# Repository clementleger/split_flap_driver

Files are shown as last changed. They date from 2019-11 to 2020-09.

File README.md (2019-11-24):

# Split flap board

Split flap display board for 28BYJ-48 motors
After seeing this design on thingiverse: https://www.thingiverse.com/thing:2369832
I needed to have one so I designed a board to driver multiple of these units.
The board is based on I2C IO expanders and uln2803 since I had these in my drawer.

# PCB

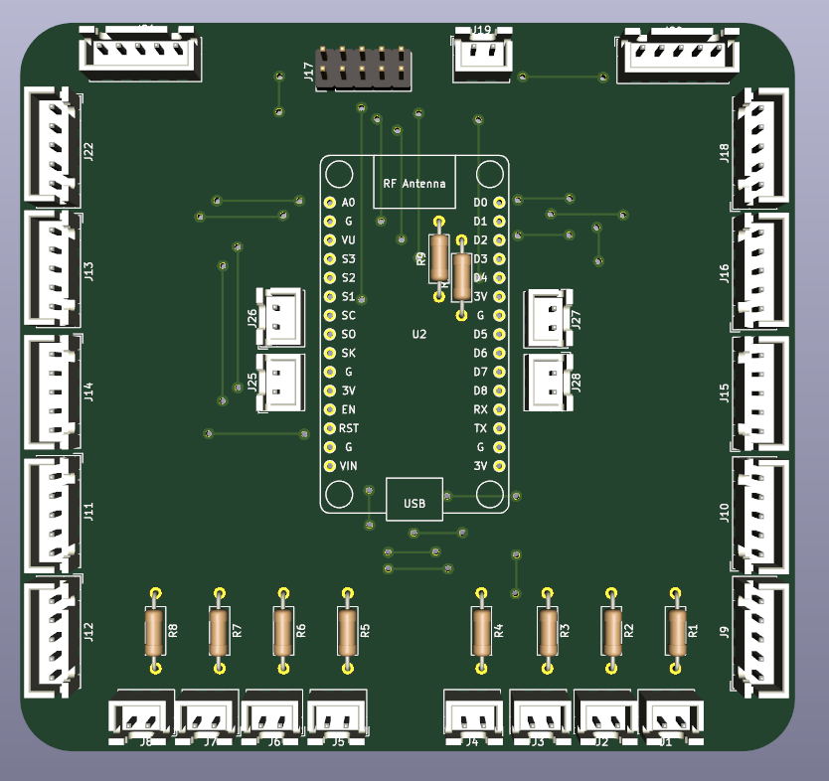
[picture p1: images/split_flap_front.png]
PCB front

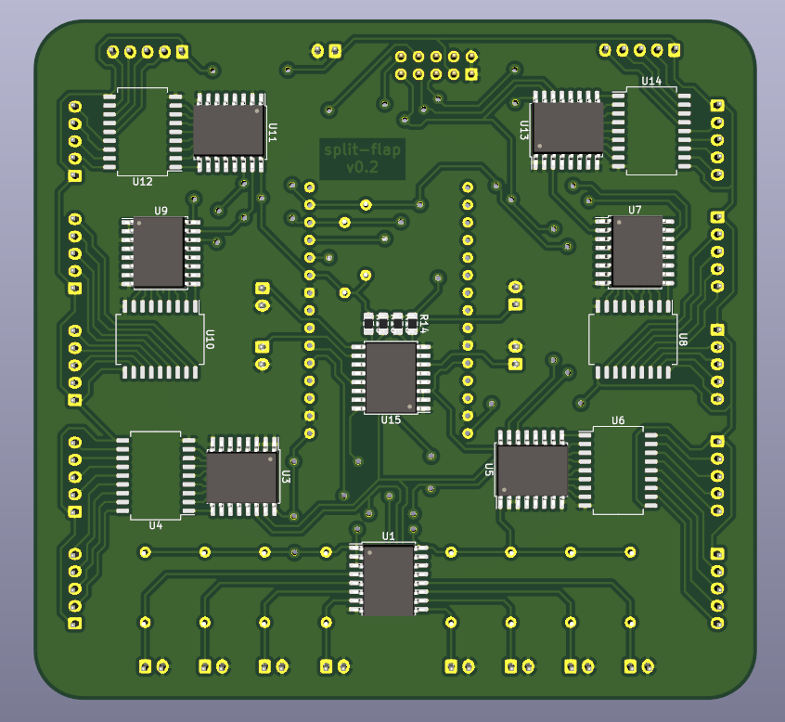
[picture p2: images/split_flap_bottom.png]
PCB bottom


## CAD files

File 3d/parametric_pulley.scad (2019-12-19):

// Parametric Pulley with multiple belt profiles
// by droftarts January 2012

// Based on pulleys by:
// http://www.thingiverse.com/thing:11256 by me!
// https://github.com/prusajr/PrusaMendel by Josef Prusa
// http://www.thingiverse.com/thing:3104 by GilesBathgate
// http://www.thingiverse.com/thing:2079 by nophead

// dxf tooth data from http://oem.cadregister.com/asp/PPOW_Entry.asp?company=915217&elementID=07807803/METRIC/URETH/WV0025/F
// pulley diameter checked and modelled from data at http://www.sdp-si.com/D265/HTML/D265T016.html


module pulley(teeth = 8,
profile = 6,

motor_shaft = 5.2,
m3_dia = 3.2,
m3_nut_hex = 1,
m3_nut_flats = 5.7,
m3_nut_depth = 2.7,	

retainer = 1,
retainer_ht = 0.4,
idler = 1,
idler_ht = 0.4,

pulley_t_ht = 12,
pulley_b_ht = 0,
pulley_b_dia = 20,
no_of_nuts = 0,
nut_angle = 90,
nut_shaft_distance = 1.2) {

// tuneable constants




//	********************************
//	** Scaling tooth for good fit **
//	********************************
/*	To improve fit of belt to pulley, set the following constant. Decrease or increase by 0.1mm at a time. We are modelling the *BELT* tooth here, not the tooth on the pulley. Increasing the number will *decrease* the pulley tooth size. Increasing the tooth width will also scale proportionately the tooth depth, to maintain the shape of the tooth, and increase how far into the pulley the tooth is indented. Can be negative */

additional_tooth_width = 0.2; //mm

//	If you need more tooth depth than this provides, adjust the following constant. However, this will cause the shape of the tooth to change.

additional_tooth_depth = 0; //mm

// calculated constants

nut_elevation = pulley_b_ht/2;
m3_nut_points = 2*((m3_nut_flats/2)/cos(30)); // This is needed for the nut trap

// The following set the pulley diameter for a given number of teeth

MXL_pulley_dia = tooth_spacing (2.032,0.254);
40DP_pulley_dia = tooth_spacing (2.07264,0.1778);
XL_pulley_dia = tooth_spacing (5.08,0.254);
H_pulley_dia = tooth_spacing (9.525,0.381);
T2_5_pulley_dia = tooth_spaceing_curvefit (0.7467,0.796,1.026);
T5_pulley_dia = tooth_spaceing_curvefit (0.6523,1.591,1.064);
T10_pulley_dia = tooth_spacing (10,0.93);
AT5_pulley_dia = tooth_spaceing_curvefit (0.6523,1.591,1.064);
HTD_3mm_pulley_dia = tooth_spacing (3,0.381);
HTD_5mm_pulley_dia = tooth_spacing (5,0.5715);
HTD_8mm_pulley_dia = tooth_spacing (8,0.6858);
GT2_2mm_pulley_dia = tooth_spacing (2,0.254);
GT2_3mm_pulley_dia = tooth_spacing (3,0.381);
GT2_5mm_pulley_dia = tooth_spacing (5,0.5715);

// The following calls the pulley creation part, and passes the pulley diameter and tooth width to that module

if ( profile == 1 ) { parametric_pulley ( "MXL" , MXL_pulley_dia , 0.508 , 1.321 ); }
if ( profile == 2 ) { parametric_pulley ( "40 D.P." , 40DP_pulley_dia , 0.457 , 1.226 ); }
if ( profile == 3 ) { parametric_pulley ( "XL" , XL_pulley_dia , 1.27, 3.051 ); }
if ( profile == 4 ) { parametric_pulley ( "H" , H_pulley_dia ,1.905 , 5.359 ); }
if ( profile == 5 ) { parametric_pulley ( "T2.5" , T2_5_pulley_dia , 0.7 , 1.678 ); }
if ( profile == 6 ) { parametric_pulley ( "T5" , T5_pulley_dia , 1.19 , 3.264 ); }
if ( profile == 7 ) { parametric_pulley ( "T10" , T10_pulley_dia , 2.5 , 6.13 ); }
if ( profile == 8 ) { parametric_pulley ( "AT5" , AT5_pulley_dia , 1.19 , 4.268 ); }
if ( profile == 9 ) { parametric_pulley ( "HTD 3mm" , HTD_3mm_pulley_dia , 1.289 , 2.27 ); }
if ( profile == 10 ) { parametric_pulley ( "HTD 5mm" , HTD_5mm_pulley_dia , 2.199 , 3.781 ); }
if ( profile == 11 ) { parametric_pulley ( "HTD 8mm" , HTD_8mm_pulley_dia , 3.607 , 6.603 ); }
if ( profile == 12 ) { parametric_pulley ( "GT2 2mm" , GT2_2mm_pulley_dia , 0.764 , 1.494 ); }
if ( profile == 13 ) { parametric_pulley ( "GT2 3mm" , GT2_3mm_pulley_dia , 1.169 , 2.31 ); }
if ( profile == 14 ) { parametric_pulley ( "GT2 5mm" , GT2_5mm_pulley_dia , 1.969 , 3.952 ); }



// Functions

function tooth_spaceing_curvefit (b,c,d)
	= ((c * pow(teeth,d)) / (b + pow(teeth,d))) * teeth ;

function tooth_spacing(tooth_pitch,pitch_line_offset)
	= (2*((teeth*tooth_pitch)/(3.14159265*2)-pitch_line_offset)) ;

// Main Module

module parametric_pulley( belt_type , pulley_OD , tooth_depth , tooth_width )
	{
	echo (str("Belt type = ",belt_type,"; Number of teeth = ",teeth,"; Pulley Outside Diameter = ",pulley_OD,"mm "));
	tooth_distance_from_centre = sqrt( pow(pulley_OD/2,2) - pow((tooth_width+additional_tooth_width)/2,2));
	tooth_width_scale = (tooth_width + additional_tooth_width ) / tooth_width;
	tooth_depth_scale = ((tooth_depth + additional_tooth_depth ) / tooth_depth) ;


//	************************************************************************
//	*** uncomment the following line if pulley is wider than puller base ***
//	************************************************************************

//	translate ([0,0, pulley_b_ht + pulley_t_ht + retainer_ht ]) rotate ([0,180,0])

	difference()
	 {	 
		union()
		{
			//base
	
			if ( pulley_b_ht < 2 ) { echo ("CAN'T DRAW PULLEY BASE, HEIGHT LESS THAN 2!!!"); } else {
				rotate_extrude($fn=pulley_b_dia*2)
				{
						square([pulley_b_dia/2-1,pulley_b_ht]);
						square([pulley_b_dia/2,pulley_b_ht-1]);
						translate([pulley_b_dia/2-1,pulley_b_ht-1]) circle(1);
				}
			}
	
		difference()
			{
			//shaft - diameter is outside diameter of pulley
			
			translate([0,0,pulley_b_ht]) 
			rotate ([0,0,360/(teeth*4)]) 
			cylinder(r=pulley_OD/2,h=pulley_t_ht, $fn=teeth*4);
	
			//teeth - cut out of shaft
		
			for(i=[1:teeth]) 
			rotate([0,0,i*(360/teeth)])
			translate([0,-tooth_distance_from_centre,pulley_b_ht -1]) 
			scale ([ tooth_width_scale , tooth_depth_scale , 1 ]) 
			{
			if ( profile == 1 ) { MXL();}
			if ( profile == 2 ) { 40DP();}
			if ( profile == 3 ) { XL();}
			if ( profile == 4 ) { H();}
			if ( profile == 5 ) { T2_5();}
			if ( profile == 6 ) { T5();}
			if ( profile == 7 ) { T10();}
			if ( profile == 8 ) { AT5();}
			if ( profile == 9 ) { HTD_3mm();}
			if ( profile == 10 ) { HTD_5mm();}
			if ( profile == 11 ) { HTD_8mm();}
			if ( profile == 12 ) { GT2_2mm();}
			if ( profile == 13 ) { GT2_3mm();}
			if ( profile == 14 ) { GT2_5mm();}
			}

			}
			
		//belt retainer / idler
		if ( retainer > 0 ) {translate ([0,0, pulley_b_ht + pulley_t_ht ]) 
		rotate_extrude($fn=teeth*4)  
		polygon([[0,0],[pulley_OD/2,0],[pulley_OD/2 + retainer_ht , retainer_ht],[0 , retainer_ht],[0,0]]);}
		
		if ( idler > 0 ) {translate ([0,0, pulley_b_ht - idler_ht ]) 
		rotate_extrude($fn=teeth*4)  
		polygon([[0,0],[pulley_OD/2 + idler_ht,0],[pulley_OD/2 , idler_ht],[0 , idler_ht],[0,0]]);}
	
		}
	   
		//hole for motor shaft
		translate([0,0,-1])cylinder(r=motor_shaft/2,h=pulley_b_ht + pulley_t_ht + retainer_ht + 2,$fn=motor_shaft*4);
				
		//captive nut and grub screw holes
	
		if ( pulley_b_ht < m3_nut_flats ) { echo ("CAN'T DRAW CAPTIVE NUTS, HEIGHT LESS THAN NUT DIAMETER!!!"); } else {
		if ( (pulley_b_dia - motor_shaft)/2 < m3_nut_depth + 3 ) { echo ("CAN'T DRAW CAPTIVE NUTS, DIAMETER TOO SMALL FOR NUT DEPTH!!!"); } else {
	
			for(j=[1:no_of_nuts]) rotate([0,0,j*nut_angle])
			translate([0,0,nut_elevation])rotate([90,0,0])
	
			union()
			{
				//entrance
				translate([0,-pulley_b_ht/4-0.5,motor_shaft/2+m3_nut_depth/2+nut_shaft_distance]) cube([m3_nut_flats,pulley_b_ht/2+1,m3_nut_depth],center=true);
	
				//nut
				if ( m3_nut_hex > 0 )
					{
						// hex nut
						translate([0,0.25,motor_shaft/2+m3_nut_depth/2+nut_shaft_distance]) rotate([0,0,30]) cylinder(r=m3_nut_points/2,h=m3_nut_depth,center=true,$fn=6);
					} else {
						// square nut
						translate([0,0.25,motor_shaft/2+m3_nut_depth/2+nut_shaft_distance]) cube([m3_nut_flats,m3_nut_flats,m3_nut_depth],center=true);
					}
	
				//grub screw hole
				rotate([0,0,22.5])cylinder(r=m3_dia/2,h=pulley_b_dia/2+1,$fn=8);
			}
		}}
	 }
	   
	}


// Tooth profile modules

module MXL()
	{
	linear_extrude(height=pulley_t_ht+2) polygon([[-0.660421,-0.5],[-0.660421,0],[-0.621898,0.006033],[-0.587714,0.023037],[-0.560056,0.049424],[-0.541182,0.083609],[-0.417357,0.424392],[-0.398413,0.458752],[-0.370649,0.48514],[-0.336324,0.502074],[-0.297744,0.508035],[0.297744,0.508035],[0.336268,0.502074],[0.370452,0.48514],[0.39811,0.458752],[0.416983,0.424392],[0.540808,0.083609],[0.559752,0.049424],[0.587516,0.023037],[0.621841,0.006033],[0.660421,0],[0.660421,-0.5]]);
	}

module 40DP()
	{
	linear_extrude(height=pulley_t_ht+2) polygon([[-0.612775,-0.5],[-0.612775,0],[-0.574719,0.010187],[-0.546453,0.0381],[-0.355953,0.3683],[-0.327604,0.405408],[-0.291086,0.433388],[-0.248548,0.451049],[-0.202142,0.4572],[0.202494,0.4572],[0.248653,0.451049],[0.291042,0.433388],[0.327609,0.405408],[0.356306,0.3683],[0.546806,0.0381],[0.574499,0.010187],[0.612775,0],[0.612775,-0.5]]);
	}
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

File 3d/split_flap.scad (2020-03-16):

include <prism.scad>
include <parametric_pulley.scad>
include <timing_belts.scad>
include <roundedcube.scad>
include <28byj-48.scad>

/* General tolenracy (should be upadate according to 3D printer) */
TOLERANCY = 0.2;
/* Tolerancy for drum axis */
AXIS_TOLERANCY = 0.3;

/* Width of flaps */
CARD_WIDTH = 54;
/* Height of flaps */
CARD_HEIGHT = 85.6;
/* THickness of flaps */
CARD_THICKNESS = 0.380;
/* Flap drum width */
FLAP_DRUM_WIDTH = CARD_WIDTH;
/* Corner around flaps */
FLAP_CORNER_RADIUS = 3;


FRONT_BOTTOM_HEIGHT = 40;
FRONT_BOTTOM_OPEN_HEIGHT = 30;
FRONT_TOP_HEIGHT = 20;

/* Number of flaps on drum */
DRUM_FLAPS_COUNT = 40;
/* Holes for flaps */
DRUM_FLAPS_HOLE_DIAMETER = 2;
assert(DRUM_FLAPS_HOLE_DIAMETER > FLAP_CUT_OFFSET);
/* Offset of flaps hole  from drum side */
DRUM_FLAPS_HOLE_OFFSET = 1;
/* Inner diameter of drum (ie tube connecting both ends) */
DRUM_INNER_DIAMETER = 40;
/* Outer diameter of drum (ie where the flaps insert) */
DRUM_OUTER_DIAMETER = 50;
/* Thickness of side of drum (ie where the flaps insert) */
DRUM_SIDE_THICKNESS = 2.5;

/* Radius of flaps where the flaps are inserted */
DRUM_FLAP_RADIUS = DRUM_OUTER_DIAMETER/2 - DRUM_FLAPS_HOLE_DIAMETER/2 - DRUM_FLAPS_HOLE_OFFSET;


FLAP_SIDE_CUT_HEIGHT = 8;
FLAP_SIDE_CUT_WIDTH = DRUM_SIDE_THICKNESS + 0.2;
FLAP_CUT_OFFSET = DRUM_FLAPS_HOLE_DIAMETER - 0.8;

/* Depth */
DRUM_AXIS_OVERLAP = 1.6;
assert(DRUM_AXIS_OVERLAP < DRUM_SIDE_THICKNESS);
/* Slack around cards (normally unnecessary) */
DRUM_AXIS_EXTRA_WIDTH = 0;

DRUM_AXIS_HEIGHT = CARD_WIDTH + DRUM_AXIS_EXTRA_WIDTH - DRUM_SIDE_THICKNESS + DRUM_AXIS_OVERLAP;
/* Thickness if tube connecting both ends both ends of drum */
DRUM_AXIS_THICKNESS = 0.8;


/* Diameter of rotation axis */
DRUM_CENTER_DIAMETER = 8;
/* Additionnal height of axis*/
DRUM_CENTER_HEIGHT = 10;
DRUM_CENTER_THICKNESS = 3;

/* Plug width */
DRUM_PLUG_WIDTH = 3;
/* Plug height */
DRUM_PLUG_HEIGHT = 6;
/* Plug thickness */
DRUM_PLUG_THICKNESS = 2;
/* Plug inside drum to connect with other end of drum */
/* This will be minus 1 to allow an exact fitting with other side */
DRUM_PLUG_COUNT = 4;

/* Number of tooth of pulley */
DRUM_PULLEY_TEETH = 25;
/* Thickness of pulley */
DRUM_PULLEY_HEIGHT = 3.5;

/* Total width of drum */
DRUM_WIDTH = CARD_WIDTH + DRUM_AXIS_EXTRA_WIDTH + DRUM_PLUG_WIDTH;

/* Magnet (for hall effect sensor) diameter */
DRUM_MAGNET_DIAMETER = 3;
/* Magnet height */
DRUM_MAGNET_HEIGHT = 3;
DRUM_MAGNET_OFFSET_FROM_CENTER = DRUM_INNER_DIAMETER/2 - 2;

$fn = 50;

/* Ziptie width */
ZIPTIE_WIDTH = 3.5;
/* Ziptie thickness */
ZIPTIE_THICKNESS = 1.4;
/* Sizeof side mount */
ZIPTIE_MOUNT_SIDE_WIDTH = 6;
/* Height of mouting base */
ZIPTIE_MOUNT_HEIGHT = 6;
/* Added thickness on top of ziptie hole */
ZIPTIE_MOUNT_ADD_THICKNESS = 1.5;
/* Full ziptie mount thickness */
ZIPTIE_MOUNT_THICKNESS = ZIPTIE_MOUNT_ADD_THICKNESS + ZIPTIE_THICKNESS;

module ziptie_mount() {
    difference() {
        union () {
            difference() {
                cube([ZIPTIE_WIDTH, ZIPTIE_MOUNT_HEIGHT , ZIPTIE_MOUNT_THICKNESS]);
                cube([ZIPTIE_WIDTH, ZIPTIE_MOUNT_HEIGHT , ZIPTIE_THICKNESS]);
            }
            translate([ZIPTIE_WIDTH + ZIPTIE_MOUNT_SIDE_WIDTH, 0, 0]) rotate([0, 0, 90]) prism(ZIPTIE_MOUNT_HEIGHT, ZIPTIE_MOUNT_SIDE_WIDTH,ZIPTIE_MOUNT_THICKNESS);
            translate([-ZIPTIE_MOUNT_SIDE_WIDTH, ZIPTIE_MOUNT_HEIGHT, 0]) rotate([0, 0, -90]) prism(ZIPTIE_MOUNT_HEIGHT, ZIPTIE_MOUNT_SIDE_WIDTH,ZIPTIE_MOUNT_THICKNESS);
        }
        translate([-ZIPTIE_MOUNT_SIDE_WIDTH, ZIPTIE_MOUNT_HEIGHT/2 - ZIPTIE_WIDTH/2, 0]) cube([ZIPTIE_WIDTH + 2 * ZIPTIE_MOUNT_SIDE_WIDTH, ZIPTIE_WIDTH , ZIPTIE_THICKNESS + SMALL_TOLERANCY]);
    }
}


module hole(width, height, thickness)
{
    cylinder(d = width, h = thickness, $fn = 30);
    translate([-width / 2, 0, 0]) cube([width, height, thickness]);
    
    translate([0, height, 0]) cylinder(d = width, h = thickness, $fn = 30);
}

module drum_plug(tolerancy = 0) 
{
    translate([-DRUM_PLUG_WIDTH/2 - tolerancy/2, 0, -DRUM_PLUG_HEIGHT]) {
        cube([DRUM_PLUG_WIDTH + tolerancy, DRUM_PLUG_THICKNESS + tolerancy, DRUM_PLUG_HEIGHT]);
        translate([0, DRUM_PLUG_THICKNESS, 0]) rotate([180, 0, 0]) prism(DRUM_PLUG_WIDTH, DRUM_PLUG_THICKNESS, DRUM_PLUG_HEIGHT / 2);
    }
}

module drum_end_with_holes()
{
    difference() {
        cylinder(d = DRUM_OUTER_DIAMETER, h = DRUM_SIDE_THICKNESS);
        /* Flaps holes */
        for (hole=[1:DRUM_FLAPS_COUNT])
            rotate([0, 0, hole * (360/DRUM_FLAPS_COUNT)  ]) translate([DRUM_FLAP_RADIUS, 0, 0]) cylinder(d = DRUM_FLAPS_HOLE_DIAMETER, h = DRUM_SIDE_THICKNESS);
        /* Axis */
        cylinder(d = DRUM_CENTER_DIAMETER, h = DRUM_SIDE_THICKNESS);
    }
}

module clipsable_male_part(width, height, thickness, clip_count = 5, clip_height = 5, clip_bottom_width = 8, clip_top_width = 10)
{
    difference() {
        linear_extrude(thickness) {
            square([width, height]);
            for (clips=[0:clip_count+1]) {
                translate([clips * (width / (clip_count + 1)), height]) polygon(points = [[clip_bottom_width/2, 0],[clip_top_width/2, clip_height],[-clip_top_width/2, clip_height],[-clip_bottom_width/2, 0]]);
            }
        }
        /* Remove sides */
        translate([-clip_top_width /2, 0, 0]) cube([clip_top_width/2, height + clip_height, thickness]);
        translate([width, 0, 0]) cube([clip_top_width/2, height + clip_height, thickness]);
    }
}

module drum_side(tolerancy = 0)
{
    /* Base with holes for flaps */
    drum_end_with_holes();

    difference() {
        cylinder(d = DRUM_CENTER_DIAMETER + DRUM_CENTER_THICKNESS, h = DRUM_CENTER_HEIGHT, $fn = 50);
        cylinder(d = DRUM_CENTER_DIAMETER, h = DRUM_CENTER_HEIGHT);
    }
    /* Axis */
    difference() {
        cylinder(d = DRUM_INNER_DIAMETER + tolerancy/2, h = DRUM_AXIS_HEIGHT);
        cylinder(d = DRUM_INNER_DIAMETER - DRUM_AXIS_THICKNESS*2 - tolerancy/2, h = DRUM_AXIS_HEIGHT);
    }
    /* Little plugs on top of axis */
    for (hole=[1:DRUM_PLUG_COUNT - 1])
            rotate([0, 0, hole * (360/DRUM_PLUG_COUNT)]) translate([0, -DRUM_INNER_DIAMETER/2 + DRUM_AXIS_THICKNESS, DRUM_AXIS_HEIGHT]) drum_plug(tolerancy);
}

module drum_with_magnet()
{
    difference() {
        drum_side();
        
        /* Magnet hole */
        translate([DRUM_MAGNET_OFFSET_FROM_CENTER - DRUM_MAGNET_DIAMETER/2 - DRUM_AXIS_THICKNESS, 0, 0]) cylinder(d = DRUM_MAGNET_DIAMETER, h = DRUM_MAGNET_HEIGHT);
    }
}

module drum_with_belt()
{
    difference() {
        translate([0, 0, CARD_WIDTH + DRUM_AXIS_EXTRA_WIDTH - DRUM_SIDE_THICKNESS]) {
            drum_end_with_holes();
            translate([0, 0, DRUM_SIDE_THICKNESS]) pulley(teeth = DRUM_PULLEY_TEETH, profile = 12, motor_shaft = DRUM_CENTER_DIAMETER, pulley_t_ht = DRUM_PULLEY_HEIGHT);
        }
       
    drum_side(TOLERANCY);
    }
}

module cube_rounded(width, height, thickness)
{
    cube([width, height, thickness]);
    translate([0, height, 0]) cylinder(r = width, h = thickness ); 
}

module flap()
{
    difference() {
        hull() {
            cube([CARD_WIDTH, CARD_HEIGHT/2 - FLAP_CORNER_RADIUS, CARD_THICKNESS]);
            translate([FLAP_CORNER_RADIUS, CARD_HEIGHT/2 - FLAP_CORNER_RADIUS, 0]) cylinder(r = FLAP_CORNER_RADIUS, h = CARD_THICKNESS);
            translate([CARD_WIDTH - FLAP_CORNER_RADIUS, CARD_HEIGHT/2 - FLAP_CORNER_RADIUS, 0]) cylinder(r = FLAP_CORNER_RADIUS, h = CARD_THICKNESS);
        }
        translate([CARD_WIDTH, FLAP_CUT_OFFSET, 0]) mirror([1, 0, 0]) cube_rounded(FLAP_SIDE_CUT_WIDTH,FLAP_SIDE_CUT_HEIGHT,CARD_THICKNESS);
        translate([0, FLAP_CUT_OFFSET, 0]) cube_rounded(FLAP_SIDE_CUT_WIDTH,FLAP_SIDE_CUT_HEIGHT,CARD_THICKNESS);
    }
}

HANGING_FLAPS_COUNT = DRUM_FLAPS_COUNT/2;

module flaps()
{
    /* Flaps hanging in the bottom of the drum */
    for (flap=[0:HANGING_FLAPS_COUNT-1]) {
        translate([DRUM_FLAP_RADIUS * sin(flap * (360 / DRUM_FLAPS_COUNT)), DRUM_FLAP_RADIUS * cos(flap * (360 / DRUM_FLAPS_COUNT)), DRUM_AXIS_EXTRA_WIDTH/2]) rotate([0, 0, -90]) 
    rotate([0, -90, 0])  flap();
    }
    for (flap=[HANGING_FLAPS_COUNT:DRUM_FLAPS_COUNT - 1]) {
        translate([DRUM_FLAP_RADIUS * sin(flap * (360 / DRUM_FLAPS_COUNT)), DRUM_FLAP_RADIUS * cos(flap * (360 / DRUM_FLAPS_COUNT)), DRUM_AXIS_EXTRA_WIDTH/2]) rotate([0, 0, - (360 - 90) - flap * (360 / (DRUM_FLAPS_COUNT - 1))]) 
    rotate([0, -90, 0])  flap();
    }
    
}

module drum()
{
    color("grey") drum_side();
    color("grey") drum_with_belt();
    color("white") flaps();
}

/* Size of bottom border */
DISP_BOTTOM_SIZE = 12;
/* Size of top border */
DISP_TOP_SIZE = 16;
/* Add some slack to sides */
DISP_BORDER_ADJUST = 0.8;
DISP_BORDER_SIZE = DRUM_PULLEY_HEIGHT + DISP_BORDER_ADJUST;
assert(DISP_BORDER_SIZE >= DRUM_PULLEY_HEIGHT);

/* Thickness of front part */
FRONT_THICKNESS = 3;
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

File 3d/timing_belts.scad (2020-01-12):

/*Parametric belting section generator 
 * types GT2 2mm T2.5 T5 T10 MXL
 *
 * (c) ALJ_rprp
 *
 * Derived from http://www.thingiverse.com/
 * thing:19758 By The DoomMeister
 * thing:16627 by Droftarts
 *
 * licence GPL 2.1 or later
 *
 * deal properly with ends
 * allow circular segments
 * length is given in mm not nb of teeth
 * belt is centered at z=0 and extend along x
 * 
 * TODO : add ofset for cosmetic teeth liaisons between segments
 *
 * usage :
 * belt_angle(prf = tT2_5, rad=25, bwdth = 6, angle=90,fn=128)
 * belt_len  (prf = tT2_5, belt_width = 6, len = 10)
 */


// profiles
tGT2_2=0;
tT2_5	=1;
tT5	=2;
tT10	=3;
tMXL	=4;

module test_belt() {
	translate([-00.5,0,5.5])cube([1,40,1]);
	
	belt_len(profile = tT10, belt_width = 10, len = 100);
	translate([0,0,-20])color("red")belt_len(profile = tT5, belt_width = 10, len = 100);
	translate([0,0,-40])color("green")belt_len(profile = tT2_5, belt_width = 10, len = 80);
	translate([0,0,-60])color("blue")belt_len(profile = tGT2_2, belt_width = 10, len = 100);
	translate([0,0,-80])color("orange")belt_len(profile = tMXL, belt_width = 10, len = 100);
	
	translate([0,0,-0])  belt_angle(tT10,20,10,180);
	translate([0,0,-20]) belt_angle(tT5,15,10,90);
	translate([0,0,-40]) belt_angle(tT2_5,25,10,120);
	translate([0,0,-60]) belt_angle(tGT2_2,30,10,40);
	translate([0,0,-80]) belt_angle(tMXL,30,10,40);

	
	translate([0,0,-100])color("aquamarine") {
		belt_len(tT2_5,10, 50);
		translate([50,30,0]) rotate([0,0,180]) belt_len(tT2_5,10,50);
		translate([ 0,30,0]) rotate([0,0,180]) belt_angle(tT2_5,15,10,180);
		translate([50,0,0]) rotate([0,0,0]) belt_angle(tT2_5,15,10,180);
	}
}

/* there is no partial rotate extrude in scad, hence the workaround
 * note that the pie slice will silently drop angles > 360 */
module p_slice(radius, angle,height,back_t=0.6) {
	pt_slc = [[0,radius],
		 		 [0 ,-back_t],
		 		 [radius,-back_t],
		 		 [radius+back_t,radius],
		 		 [radius+back_t,radius*2],
				 [0,radius*2+back_t],
				 [-radius-back_t,radius*2+back_t],
				 [-radius-back_t,radius],
				 [-radius-back_t,-back_t],
		 		 [(radius+back_t)*sin(angle),(radius+back_t)*(1-cos(angle))-back_t]];

	if (angle<=90) {
		linear_extrude(height+0.2, center=true)
			polygon( points = pt_slc, 
						paths=[[0,1,2,9]]);
	}else if (angle<=180){
		linear_extrude(height+0.2, center=true)
			polygon( points = pt_slc,  
						paths=[[0,1,2,3,4,9]]);
	}else if (angle<=270){
		linear_extrude(height+0.2, center=true)
			polygon( points = pt_slc,  
						paths=[[0,1,2,3,4,5,6,9]]);
	}else if (angle<360) {
		linear_extrude(height+0.2, center=true)
			polygon( points = pt_slc,  
						paths=[[0,1,2,3,4,5,6,7,8,9]]);
	}
}

dp=5;

module belt_angle(prf = tT2_5, rad=25, bwdth = 6, angle=90,fn=128) {
	av=360/2/rad/3.14159*tpitch[prf];
	bk=bk_thick[prf];

	nn=ceil(angle/av);
	ang=av*nn;
	intersection(){
	p_slice(rad,angle,bwdth,bk_thick[prf]);
		union () {
			for( i = [0:nn]){
				translate ([0,rad,-bwdth/2])rotate ([0,0,av*i])translate ([0,-rad,0])
						draw_tooth(prf,0,bwdth);
		}
		translate ([0,rad,-bwdth/2]) rotate_extrude(angle = 90, $fn=fn)
												polygon([[rad,0],[rad+bk,0],[rad+bk,bwdth],[rad,bwdth]]);
		}
	}
}

//Outer Module
module belt_len(profile = tT2_5, belt_width = 6, len = 10){
	if ( profile == tT2_5 ) { _belt_len(prf=profile,len = len,bwdth = belt_width);}
	if ( profile == tT5 )   { _belt_len(prf=profile,len = len,bwdth = belt_width);}
	if ( profile == tT10 )  { _belt_len(prf=profile,len = len,bwdth = belt_width);}
	if ( profile == tMXL )	{ _belt_len(prf=profile,len = len,bwdth = belt_width);}
	if ( profile == tGT2_2 ){ _belt_len(prf=profile,len = len,bwdth = belt_width);}
}

//inner module
module _belt_len(prf = -1, len = 10, bwdth = 5) {

	n=ceil(len/tpitch[prf]);

	translate ([0,0,-bwdth/2]) intersection() {
		union(){
			for( i = [0:n]) {
				draw_tooth(prf,i,bwdth);
			}
		translate([-1,-bk_thick[prf],0])cube([len+1,bk_thick[prf],bwdth]);
		}
	translate([0,-bk_thick[prf],0])cube([len,max_h[prf]+bk_thick[prf],bwdth]);
	}
}

module draw_tooth(prf,i,bwdth) {
				if ( prf == tT2_5 ) { translate([tpitch[prf]*i,0,0])
													linear_extrude(height=bwdth) polygon(pf_T2_5);}
				if ( prf == tT5 ) { translate([tpitch[prf]*i,0,0])
													linear_extrude(height=bwdth) polygon(pf_T5);}
				if ( prf == tT10 ) { translate([tpitch[prf]*i,0,0])
													linear_extrude(height=bwdth) polygon(pf_T10);}
				if ( prf == tMXL ) { translate([tpitch[prf]*i,0,0])
													linear_extrude(height=bwdth) polygon(pf_MXL);}
				if ( prf == tGT2_2 ) { translate([tpitch[prf]*i,0,0])
													linear_extrude(height=bwdth) polygon(pf_GT2_2);}
}

/************************************
 *				DATA TABLES					*
 ************************************/
tpitch = [2,2.5,5,10,2.032];
bk_thick=[0.6,0.6,1,2,0.64];
max_h=[0.76447, 0.699911, 1.189895, 2.499784, 0.508035];
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

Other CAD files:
3d/28byj-48.scad
3d/prism.scad

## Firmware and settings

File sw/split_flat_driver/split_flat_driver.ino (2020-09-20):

//#define HAVE_WIFI

#include <ESP8266WiFi.h>
#include <ESP8266WebServer.h>
#include <ESP8266mDNS.h>
#include <Arduino.h>
#include <Wire.h>
#include <SPI.h>
#include "c_types.h"
#ifdef HAVE_WIFI
#include "wifi_params.h"
#endif

#define ARRAY_SIZE(arr) (sizeof(arr) / sizeof((arr)[0]))
#define PCF8574_BASE_ADDR	0x20
#define SPI_FREQUENCY	1000000
#define SPI_SR_CS	D8

/* Shared interrupt */
#define INPUT_EXP_INT	D3
#define INPUT_EXP1_ADDR	(PCF8574_BASE_ADDR)

#define STEP_DELAY_US	2000
#define NUM_COILS	4
#define MAX_CHARS	64

#define PCF8574_INPUT_COUNT	8

#define STEPS_PER_REV		2038
#define STEPS_PER_LETTER	(STEPS_PER_REV / ARRAY_SIZE(flaps_chars))

#define SPLITFLAP_DNS_NAME	"splitflap"

enum display_state {
	DISPLAY_IDLE,
	DISPLAY_SYNCING,
	DISPLAY_UPDATING,
	DISPLAY_SERIAL_RECV,
};

static const char flaps_chars[] =
{
	'a', 'b', 'c', 'd', 'e', 'f', 'g', 'h', 'i', 'j', 'k', 'l', 'm', 'n', 'o',
	'p', 'q', 'r', 's', 't', 'u', 'v', 'w', 'x', 'y', 'z',
	'1', '2', '3', '4', '5', '6', '7', '8', '9',
	'#', ',', ':', '*', ' '
};

#define CHARS_COUNT	ARRAY_SIZE(flaps_chars)

struct split_flat_con {
	u16 motor_coils_shift[NUM_COILS];
	u8 input_shift;
	u8 cur_coil;
	u8 current_char;
	u8 start_char;
	u8 target_char;
	u8 chars_count;
	const char *chars;
	u32 steps_to_do;
	u8 start_adjust_steps;
};


static struct split_flat_con split_flaps[] = {
	{{3, 2, 1, 0}, 0, 0, ' ', 'b', ' ', CHARS_COUNT, flaps_chars, 0, 0},
	{{4, 5, 6, 7}, 1, 0, ' ', ' ', ' ', CHARS_COUNT, flaps_chars, 0, 0},
	//~ {{8, 9, 10, 11}, 2, 0, ' ', ' ', ' ', CHARS_COUNT, flaps_chars, 0, 0},
	//~ {{12, 13, 14, 15}, 3, 0, ' ', ' ', ' ', CHARS_COUNT, flaps_chars, 0, 0},
	//~ {{16, 17, 18, 19}, 4, 0, ' ', ' ', ' ', CHARS_COUNT, flaps_chars, 0, 0},
	//~ {{20, 21, 22, 23}, 5, 0, ' ', ' ', ' ', CHARS_COUNT, flaps_chars, 0, 0},
	//~ {{24, 25, 26, 27}, 6, 0, ' ', ' ', ' ', CHARS_COUNT, flaps_chars, 0, 0},
	//~ {{28, 29, 30, 31}, 7, 0, ' ', ' ', ' ', CHARS_COUNT, flaps_chars, 0, 0},
};

//~ #define SPLIT_FLAP_COUNT ARRAY_SIZE(split_flaps)
#define SPLIT_FLAP_COUNT 1
#define SPLIT_FLAT_MASK		((1 << SPLIT_FLAP_COUNT) - 1)

/* Bitmask which will */
static u8 shift_register_buffer[ARRAY_SIZE(split_flaps) / 2] = {0};

struct pcf_input {
	int pin;
	uint8_t addr;
	uint8_t width;
};

static struct pcf_input pcf_inputs[] = 
{
	{INPUT_EXP_INT, INPUT_EXP1_ADDR, PCF8574_INPUT_COUNT},
};

ESP8266WebServer server(80);
static void disp_string(String str);
static unsigned short step_delay_us = STEP_DELAY_US;

static int display_state = DISPLAY_IDLE;
String display_str;

static void display_set_state(int state)
{
	Serial.print("settings display state to ");
	Serial.println(state);
	display_state = state;
}

/**
 * Server part
 */
 
int server_feed_parts = 0;

static void server_handle_root()
{
	server.send(200, "text/plain", "split-flap is online !");
}

static void server_handle_sync()
{
	if (display_state != DISPLAY_IDLE) {
		server.send(503, "text/plain", "Busy !");
		return;
	}

	display_set_state(DISPLAY_SYNCING);
	server.send(200, "text/plain", "Busy !");
}

static void server_handle_disp()
{
	if (display_state != DISPLAY_IDLE) {
		server.send(503, "text/plain", "Busy !");
		return;
	}

	if (!server.hasArg("string")) {
		server.send(400, "text/plain", "Missing string parameter");
		return;
	}

	String str_arg = server.arg("string");
	if (str_arg.length() > SPLIT_FLAP_COUNT) {
		server.send(400, "text/plain", "Maximum string size exceeded");
		return;
	}

	display_str = str_arg;
	display_set_state(DISPLAY_UPDATING);

	server.send(200, "text/plain", "Displaying");
}

static void server_handle_not_found()
{
	String message = "File Not Found\n\n";
	server.send(404, "text/plain", message);
}

static void server_init()
{

	if (MDNS.begin(SPLITFLAP_DNS_NAME))
		Serial.println("MDNS responder started");

	server.on("/", server_handle_root);
	server.on("/disp", server_handle_disp);
	server.on("/sync", server_handle_sync);
	server.onNotFound(server_handle_not_found);
	server.begin();
}

static void server_update()
{
	server.handleClient();
	MDNS.update();
}

/**
 * Serial part
 */
#define SERIAL_COMMAND_LEN	64
static char serial_command[SERIAL_COMMAND_LEN + 1] = {0};
static byte serial_command_idx = 0;

static int serial_read_chars()
{
	while(Serial.available() > 0) {
		serial_command[serial_command_idx] = Serial.read();
		if (serial_command[serial_command_idx] == '\n') {
			serial_command[serial_command_idx] = '\0';
			serial_command_idx = 0;
			return 1;
		}
		serial_command_idx++;
		if (serial_command_idx > SERIAL_COMMAND_LEN) {
			Serial.println("String too long !");
			serial_command_idx = 0;
		}
	}

	return 0;
}

static void serial_parse_command()
{
	char *n;
	int flap, steps;

	if (strcmp(serial_command, "sync") == 0) {
		display_set_state(DISPLAY_SYNCING);
	} else if (strncmp(serial_command, "disp", strlen("disp")) == 0) {
		n = strchr(serial_command, ';');
		n++;
		disp_string(n);
	}else if (strncmp(serial_command, "speed", strlen("speed")) == 0) {
		n = strchr(serial_command, ';');
		n++;
		step_delay_us = atoi(n);
		Serial.print("Setting speed to ");
		Serial.println(step_delay_us);
	} else if (strncmp(serial_command, "step", strlen("step")) == 0) {
		n = strchr(serial_command, ';');
		if (!n)
			Serial.println("step;flap;count");
		n++;
		flap = atoi(n);
		n = strchr(serial_command, ';');
		if (!n)
			Serial.println("step;flap;count");
		n++;
		steps = atoi(n);
	} else {
		Serial.print("Invalid command: ");
		Serial.println(serial_command);
	}
}

static void serial_state_step()
{
	int ret;

	ret = serial_read_chars();
	if (ret)
		serial_parse_command();
	
}

/**
 * Core part
 */

static int get_letter_offset(char l)
{
	for (uint8_t i = 0; i < ARRAY_SIZE(flaps_chars); i++) {
		if (flaps_chars[i] == l)
			return i;
	}

	return -1;
}

static int get_steps_between_letter(char current, char target)
{
	int cur_offset = get_letter_offset(current);
	int target_offset = get_letter_offset(target);
	int steps;

	Serial.print("Distance between ");
	Serial.print(current);
	Serial.print(" and ");
	Serial.print(target);
	Serial.print(": ");
	
	/* We need to wrap so we will sync */
	if (target_offset < cur_offset) {
		steps = (target_offset + CHARS_COUNT) - cur_offset;
	} else {
		steps = (target_offset - cur_offset);
	}
	Serial.println(steps);

	return steps * STEPS_PER_LETTER;
}

static u64 pcf_input_status = 0;

static uint8_t read_pcf(struct pcf_input *pcf)
{
	uint8_t status;

	Wire.requestFrom(pcf->addr, (uint8_t) 1);
	while (Wire.available() < 1);

	status = Wire.read();

	return status;
}

static void check_input_status(void)
{
	uint8_t status;

	for (uint8_t i = 0; i < ARRAY_SIZE(pcf_inputs); i++) {
		struct pcf_input *pcf = &pcf_inputs[i];

		/* Interrupt is a NOT */
		if (digitalRead(pcf->pin) == HIGH)
			continue;

		status = read_pcf(pcf);

		/* Logic is inverted, ie gnd when triggered */
		pcf_input_status |= (~status << (i * PCF8574_INPUT_COUNT));
	}
}

static void reset_input_status()
{
	pcf_input_status = 0;
}

SPISettings spi_settings(SPI_FREQUENCY, MSBFIRST, SPI_MODE0);

/**
 * Drive all motor coils according to the next_value.
 */
static void flaps_update_all(void)
{
	SPI.beginTransaction(spi_settings);
	SPI.transfer(shift_register_buffer, ARRAY_SIZE(shift_register_buffer));
	SPI.endTransaction();

	/* Latch data */
	digitalWrite(SPI_SR_CS, LOW);
	digitalWrite(SPI_SR_CS, HIGH);
	digitalWrite(SPI_SR_CS, LOW);

	/* Reset buffer */
	memset(shift_register_buffer, 0, ARRAY_SIZE(shift_register_buffer));
}

static void shift_reg_set_bit(u16 bit)
{
	u16 offset = (bit / 8);

	shift_register_buffer[offset] |= (1 << (bit % 8));
}

static int flap_sync_triggered(struct split_flat_con *flap)
{
	return (pcf_input_status & (1 << flap->input_shift));
}

static int all_flaps_synced(void)
{
	return (pcf_input_status & SPLIT_FLAT_MASK) == SPLIT_FLAT_MASK;
}

static void do_flap_motor_step(struct split_flat_con *flap)
{
	int cur_coil = flap->cur_coil;
	int next_coil = flap->cur_coil + 1;

	if (next_coil > NUM_COILS)
		next_coil = 0;

	/* Full step drive */
	shift_reg_set_bit(flap->motor_coils_shift[cur_coil]);
	shift_reg_set_bit(flap->motor_coils_shift[next_coil]);

	cur_coil++;
	if (cur_coil >= NUM_COILS)
		cur_coil = 0;

	flap->cur_coil = cur_coil;
}

static unsigned int update_flaps_last_micros = 0;

static void sync_all_flaps_step(void)
{
	unsigned int cur_micros = micros(); 
	if (cur_micros - update_flaps_last_micros < step_delay_us)
		return;

	update_flaps_last_micros = cur_micros;
	for (uint8_t i = 0; i < SPLIT_FLAP_COUNT; i++) {
		struct split_flat_con *flap = &split_flaps[i];
		if (flap_sync_triggered(flap))
			continue;

		do_flap_motor_step(flap);
	}

	flaps_update_all();
}

static void reset_flaps_start_character()
{
	Serial.println("Resetting flaps to start_character");

	ESP.wdtFeed();
	for (uint8_t i = 0; i < SPLIT_FLAP_COUNT; i++) {
		struct split_flat_con *flap = &split_flaps[i];
		flap->current_char = flap->start_char;
	}
}

static void sync_reset_flaps(void)
{
	Serial.println("Resetting all flaps");
	while (!all_flaps_synced()) {
		sync_all_flaps_step();
		check_input_status();
		ESP.wdtFeed();
	}

	reset_flaps_start_character();
}

void display_sync_step()
{
	check_input_status();
	if (all_flaps_synced()) {
		Serial.println("All flaps synced !");

		/* Syncing done ! */
		reset_input_status();
		display_set_state(DISPLAY_IDLE);
		reset_flaps_start_character();
	} else {
		sync_all_flaps_step();
	}
}


void display_update_step()
{
	bool target_reached = true;
	unsigned int cur_micros = micros(); 
	if (cur_micros - update_flaps_last_micros < step_delay_us)
		return;

	update_flaps_last_micros = cur_micros;
	for (uint8_t i = 0; i < SPLIT_FLAP_COUNT; i++) {
		struct split_flat_con *flap = &split_flaps[i];

		if (flap->steps_to_do--) {
			target_reached = false;
			do_flap_motor_step(flap);
			flap->current_char = flap->target_char;
		}
	}

	flaps_update_all();

	if (target_reached)
		display_set_state(DISPLAY_IDLE);
}

static void disp_string(String str)
{
	Serial.print("Displaying text: ");
	Serial.println(str);
	for (uint8_t i = 0; i < SPLIT_FLAP_COUNT; i++) {
		struct split_flat_con *flap = &split_flaps[i];
		if (i < str.length())
			flap->target_char = str.charAt(i);
		else
			flap->target_char = ' ';

		flap->steps_to_do = get_steps_between_letter(flap->current_char,
							     flap->target_char);
		Serial.print("Flaps ");
		Serial.print(i);
		Serial.print(": ");
		Serial.print(flap->steps_to_do);
		Serial.println(" steps");
	}

	display_set_state(DISPLAY_UPDATING);
}

void setup(void)
{
	Serial.begin(115200);

#ifdef HAVE_WIFI
	Serial.println("Connecting...");
	WiFi.begin(WIFI_SSID, WIFI_PASSWORD);

	while(!WiFi.isConnected() ){
		Serial.println("Waiting for connection");
		delay(1000);
	}
	Serial.println("Connected !");
#endif
	Serial.println("Init inputs");

	pinMode(INPUT_EXP_INT, INPUT_PULLUP);

	Wire.begin(D2, D1);
	/* Configure IO expander interrupts pins as input */
	for (uint8_t i = 0; i < ARRAY_SIZE(pcf_inputs); i++) {
		struct pcf_input *in = &pcf_inputs[i];

		/* Set all pins as input */
		Wire.beginTransmission(in->addr);
		Wire.write(0xFF);
		Wire.endTransmission();
	}
	Serial.println("Init SPI");
	
	pinMode(SPI_SR_CS, OUTPUT);
	digitalWrite(SPI_SR_CS, LOW);
	SPI.begin();

	Serial.println("SPI init done");
	/* Release all motors coils */
	flaps_update_all();

	Serial.println("Init inputs");

	sync_reset_flaps();

	server_init();
	
}

void loop(void)
{
	server_update();

	switch (display_state) {
		case DISPLAY_SYNCING:
			display_sync_step();
		break;
		case DISPLAY_UPDATING:
			display_update_step();
		break;
		case DISPLAY_SERIAL_RECV:
			serial_state_step();
		break;
		default:
			if (Serial.available() > 0)
				display_set_state(DISPLAY_SERIAL_RECV);
		break;
	}
}

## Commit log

2019-11-24 Initial PCB
    [motor2x.sch, split_flap.kicad_pcb, split_flap.sch]
2019-11-25 Add missing Interrupt line
    [split_flap.kicad_pcb]
2019-11-26 hw: Supercharge PCB !
    [filemotorx2Rev.sch, motor2x.sch, split_flap.kicad_pcb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]
2019-11-27 Reroute full PCB
    [filemotorx2Rev.sch, motor2x.sch, split_flap.kicad_pcb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]
2019-11-28 hw: Route pcb completely
    [filemotorx2Rev.sch, motor2x.sch, split_flap.kicad_pcb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]
2019-11-29 More spacing between esp and input connectors
    [split_flap.kicad_pcb]
2019-12-12 Update schematic with 74HC595
    Remove PCF for output and use shift register
    [input_expander.sch, motor2x.sch, split_flap.sch]
2019-12-13 Rework PCB
    Start routing all expanders
    [input_expander.sch, motor2x.sch, split_flap.kicad_pcb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]
2019-12-16 Route new PCB completely.
    [motor2x.sch, split_flap.kicad_pcb, split_flap.sch]
2019-12-17 Add VCC for motors
    [input_expander.sch, motor2x.sch, split_flap.kicad_pcb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]
2019-12-17 Add mounting holes, logo and capacitor for +5V
    [motor2x.sch, split_flap.kicad_pcb, split_flap.sch]
2019-12-19 Add i2c pullups
    [motor2x.sch, split_flap.sch]
2019-12-19 Add openscad files for flaps drum
    [parametric_pulley.scad, prism.scad, split_flap.scad]
2020-01-01 add flaps
    [split_flap.scad]
2020-01-02 Add front part
    [split_flap.scad]
2020-01-03 Add sides
    [split_flap.scad]
2020-01-05 Add bottom part to hold motor
    [28byj-48.scad, split_flap.scad]
2020-01-05 3d: Add tolerancy for drum
    [split_flap.scad]
2020-01-07 3d: Finalize bottom, and make final adjustements
    [split_flap.scad]
2020-01-07 3d: Reduce number of teeth to allow ratio with stepper
    [split_flap.scad]
2020-01-07 3d: Modify flap to be exported
    [split_flap.scad]
2020-01-08 3d: Rework sides of slipt flap module
    [split_flap.scad]
2020-01-08 3d: Add transverse support to side
    [split_flap.scad]
2020-01-09 3d: Adjust some drum parameters
    [split_flap.scad]
2020-01-10 Add card_jig and fix various parameters of display
    [card_jig.scad, split_flap.scad]
2020-01-11 Integrate card jig in split_flap
    [card_jig.scad, split_flap.scad]
2020-01-12 Add svg for card laser cutting
2020-01-12 Add card retainer at bottom
    [split_flap.scad]
2020-01-12 3d: Add belt cutter jig
    [split_flap.scad, timing_belts.scad]
2020-01-13 3d: Adjust windows height
    [split_flap.scad]
2020-01-19 Add letters cut for laser cutting
2020-02-14 3d: Adjust some vairable to have a more powerful flapping
    [split_flap.scad]
2020-02-14 3d: modify hall effect sensor hole
    Modify it to be exactly the height of the magnet on drum.
    [split_flap.scad]
2020-02-16 hw: Add hall effect sensor pcb
    [hall_sensor.kicad_pcb, hall_sensor.sch]
2020-03-16 Add top part of box
    [split_flap.scad]
2020-03-16 Rework ino to use shift registers
    [split_flat_driver.ino]
2020-03-19 Add i2c pullup resistors on pcb...
    [split_flap.kicad_pcb, split_flap.sch]
2020-09-20 sw: fix various things, first working sync
    [split_flat_driver.ino]
